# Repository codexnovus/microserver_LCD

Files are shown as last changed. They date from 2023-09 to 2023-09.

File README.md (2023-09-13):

# microserver_LCD
An LCD display for the microserver. See the documentation inside each folder for more information, or go to the [Hackaday project page](https://hackaday.io/project/192756-lcd-display-for-a-hp-g7-microserver)

Every folder contain its own documentation:
* arduino: schematics, and project files for the arduino part
* enclosure: 3D model and ready-to-print files
* node: Node.js project to run the system from the PC
* references: reference files, documentation, links and credits

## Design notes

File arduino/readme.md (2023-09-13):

# Arduino Code

This part of the project borrows heavily from [arduino-lcdproc](https://github.com/TimeTravel-0/arduino-lcdproc) plus some tutorials.

The sketch initializes the screen, and has a timeout function when is not receiving data.

It also reads the status of the buttons and sends A or B whenever one is pressed.

Is not really complex, but doesn't need to be.

Using this script also has the nice extra bonus of being compatible with LCDProc serializer mode, though the buttons won't be supported.

# The circuit

The circuit is fairly simple, the only complication is finding the proper resistance wiper for your project. Mine could have used a 30K. At 20K it simply goes from nothing until you reach like 90% and then it kicks right in into the visible territory. 

My screen did not have backlight: If yours has, it may be a good idea to put a resistor in the BLA pin. Arduino tutorials recommend 220 ohm.

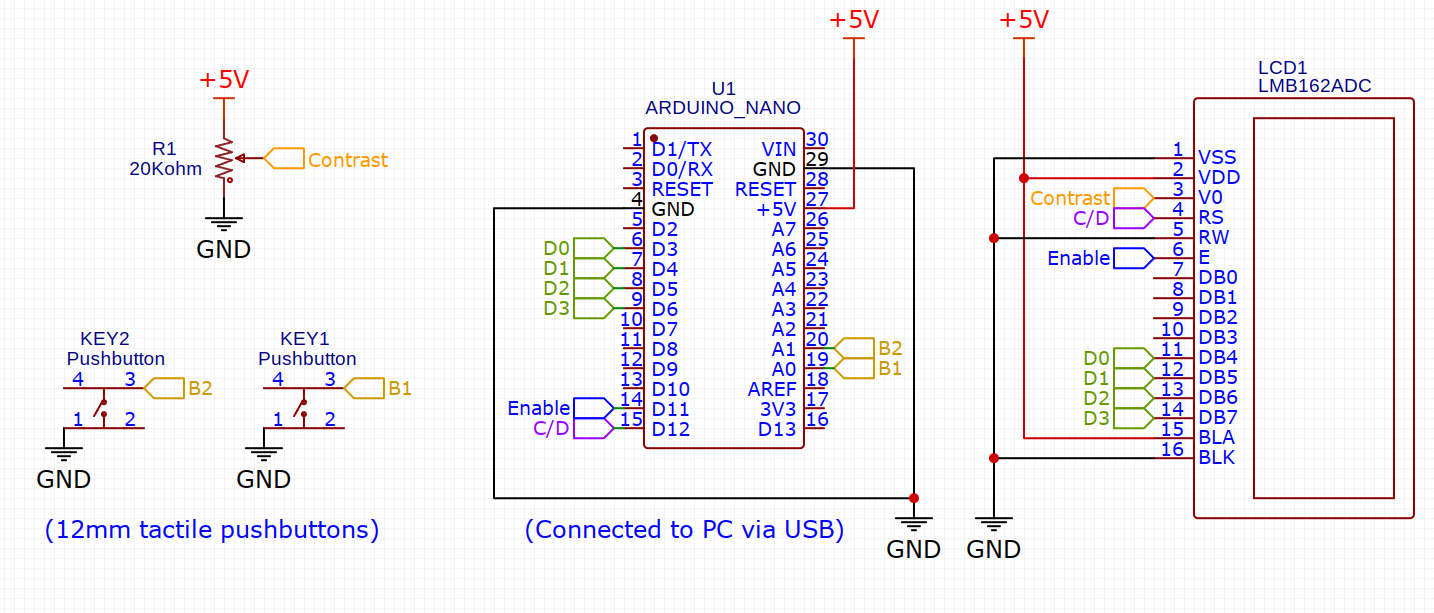
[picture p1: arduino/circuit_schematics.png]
The schematic


Originally This project embedded the circuit directly into the screen but I had issues routing the USB cable so I ended up separating the circuit and routing everything with cables. On the other hand this simplifies cable routing enormously.

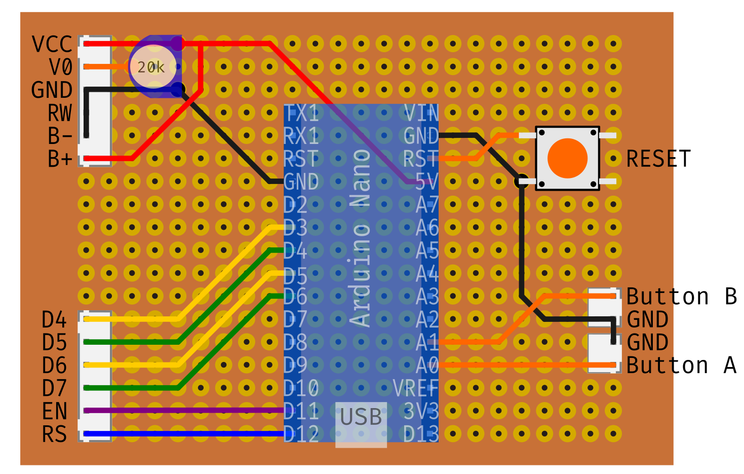
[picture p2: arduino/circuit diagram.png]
The diagram


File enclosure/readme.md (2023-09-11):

# The 3D model
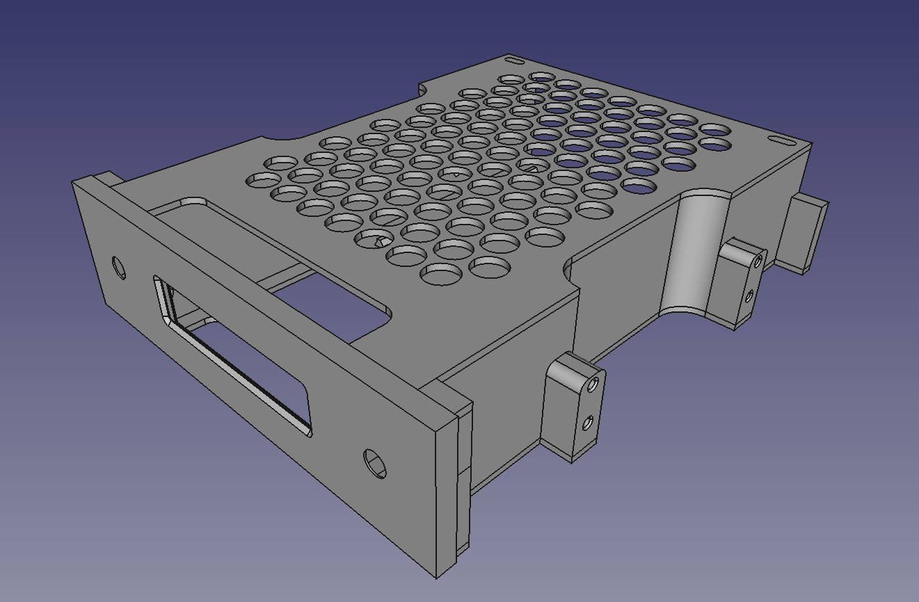
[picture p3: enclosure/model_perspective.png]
The model

The model consists of a base that (loosely) follows the CD-ROM standard measures that you can find on the "References" folder, a faceplate that houses the screen and the buttons, and a top cover that ties everything in a nice package. It has a space for fitting a 2.5 inch hard drive.

Everything is either press fitted, or secured with M3/M4 screws.

One could modify only the faceplate to fit a different LCD if needed, though most HD44780 clones I've seen have similar measures.

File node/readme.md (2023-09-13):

# The computer-side app
This app is written in node.js and requires the serialport and systeminformation libraries. The app is written for Linux in mind but there should be no reason it cannot run in Windows by changing the port reference, and modifying the screen functions that handle OS-specific situations, like the hard disk stats. Systeminformation tries to be as OS-agnostic as possible so things like CPU, Memory, Network Interfaces... should work out of the box.

## The app structure
The app will open the serial port defined in the lcd object and will call a _screen function_ once per second. It will also listen for pushbutton events that will change which screen is active.

## The screen functions
The screen functions are self contained: They retrieve the data from systeminformation and update the LCD screen.
There are currently four:
* screen_hostname: displays current local IP and hostname
* screen_diskinfo: retrieves hard drive usage and label or path and displays the first two.
* screen_heartbeat: displays CPU, RAM, and Network usage
* screen_uptime: displays system uptime

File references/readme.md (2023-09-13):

# Documents
* SF-8551.PDF: Specifications for CD-ROM drives. The last two pages include all measurements you need to make your own 5 1/2 inch half height enclosure.
* HD44780U.PDF: Datasheet for the original chip. Includes specific documentation about how characters are stored that most pages ignore.

# Links
* [systeminformation node library](https://systeminformation.io): This is the library I used to collect info from the system
* [serialport library](https://serialport.io): This is the library that enables node.js interface with the LCD

# Images
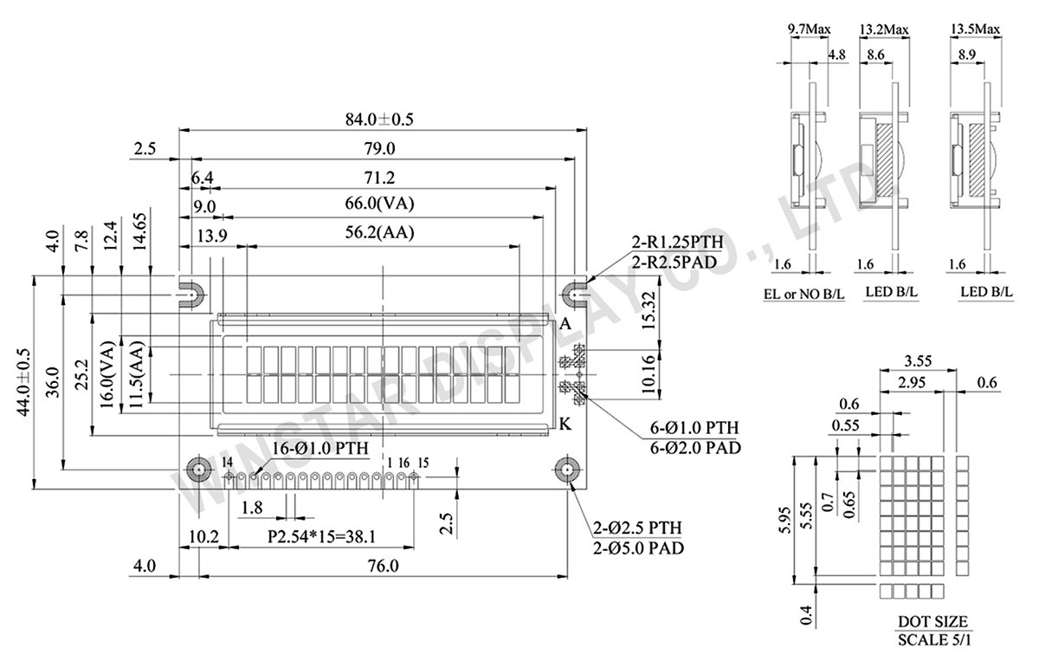
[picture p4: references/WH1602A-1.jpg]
LCD Specs

Physical specifications for the 1602 LCD. Most follow similar patterns. I checked mine against those with a caliper and fit decently.

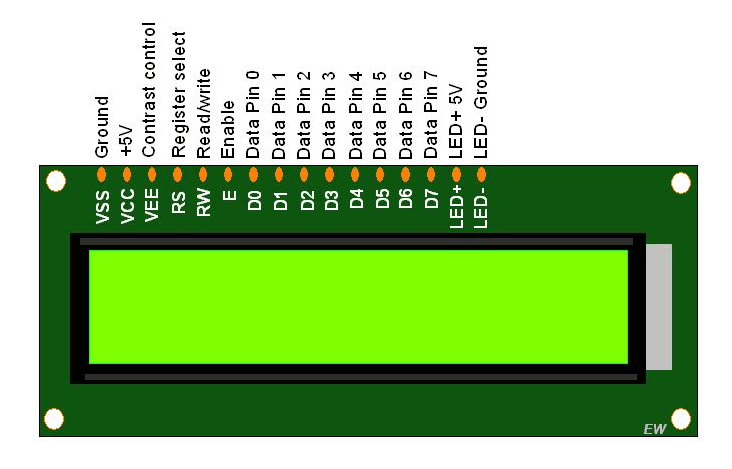
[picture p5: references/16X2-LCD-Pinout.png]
LCD Pinout

LCD pinout. Most of not all LCDs have the same pinout, but also they lack any kind of labeling so it is a good idea to have it handy.

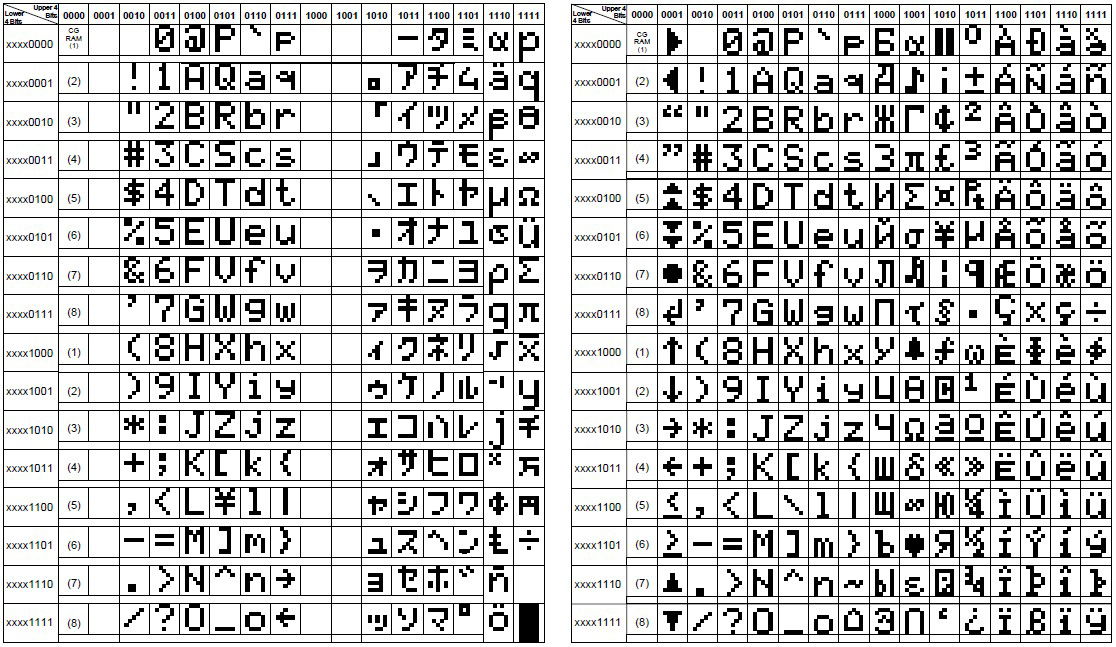
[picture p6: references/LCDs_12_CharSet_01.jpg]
LCD Charset

Charset map for the two more common ROMS.

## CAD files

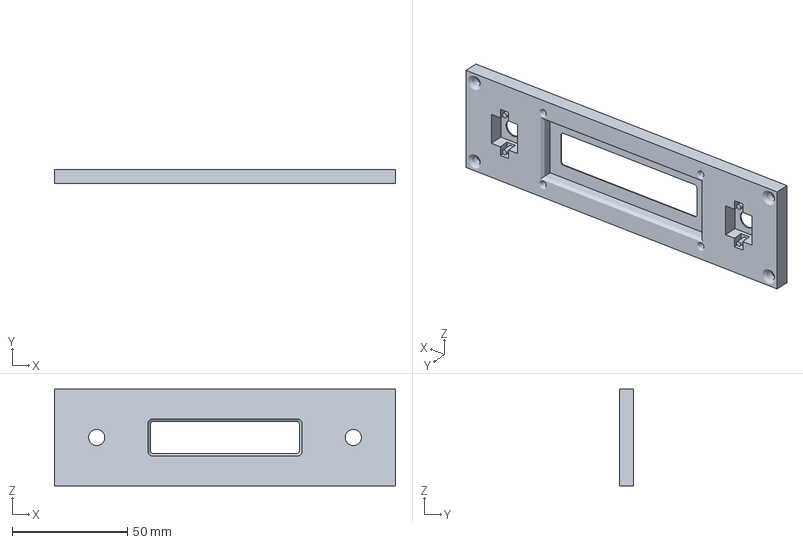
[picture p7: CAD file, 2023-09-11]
enclosure/LCD_Enclosure-Front Plate.3mf
148.0 x 6.00 x 42.0 mm

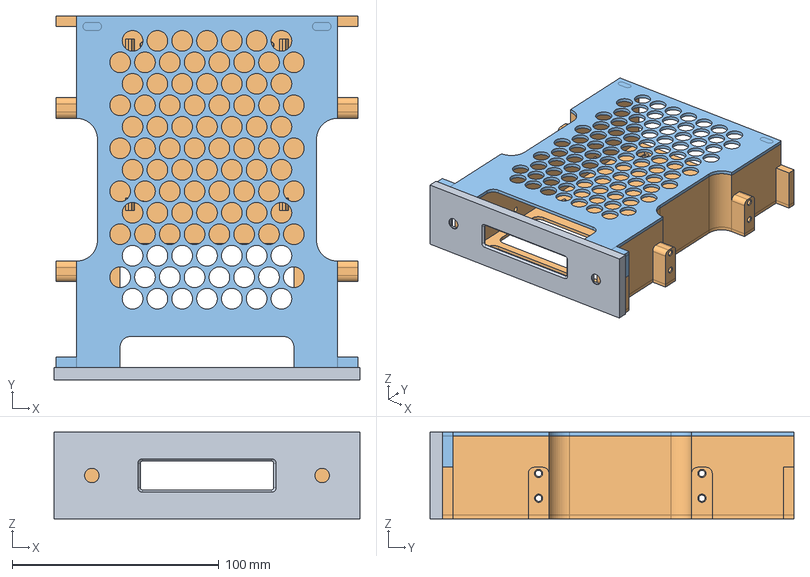
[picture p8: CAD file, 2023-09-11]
enclosure/LCD_Enclosure.FCStd
148.0 x 176.0 x 42.0 mm
Front Plate
Bottom Plate
Top Plate

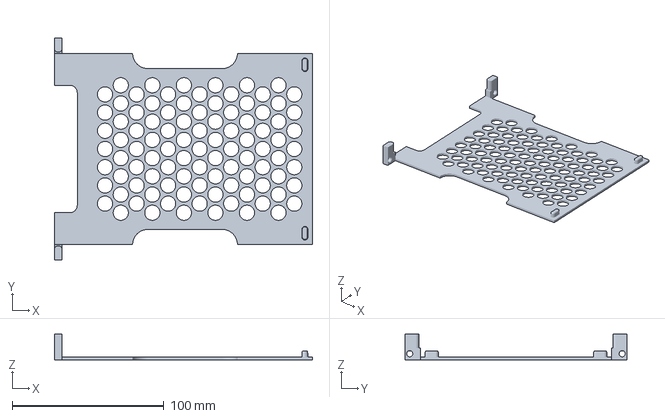
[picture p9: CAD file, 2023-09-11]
enclosure/LCD_Enclosure-Top Plate.3mf
170.0 x 146.0 x 17.0 mm

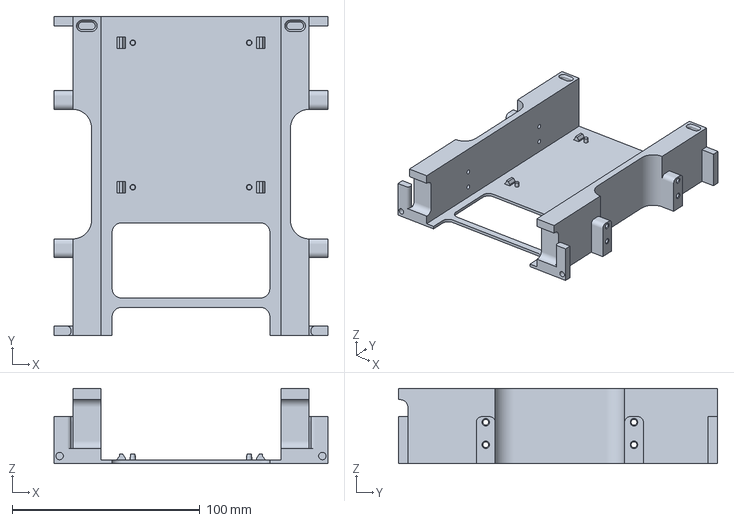
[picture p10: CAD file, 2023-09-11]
enclosure/LCD_Enclosure-Bottom Plate.3mf
146.0 x 170.0 x 40.0 mm

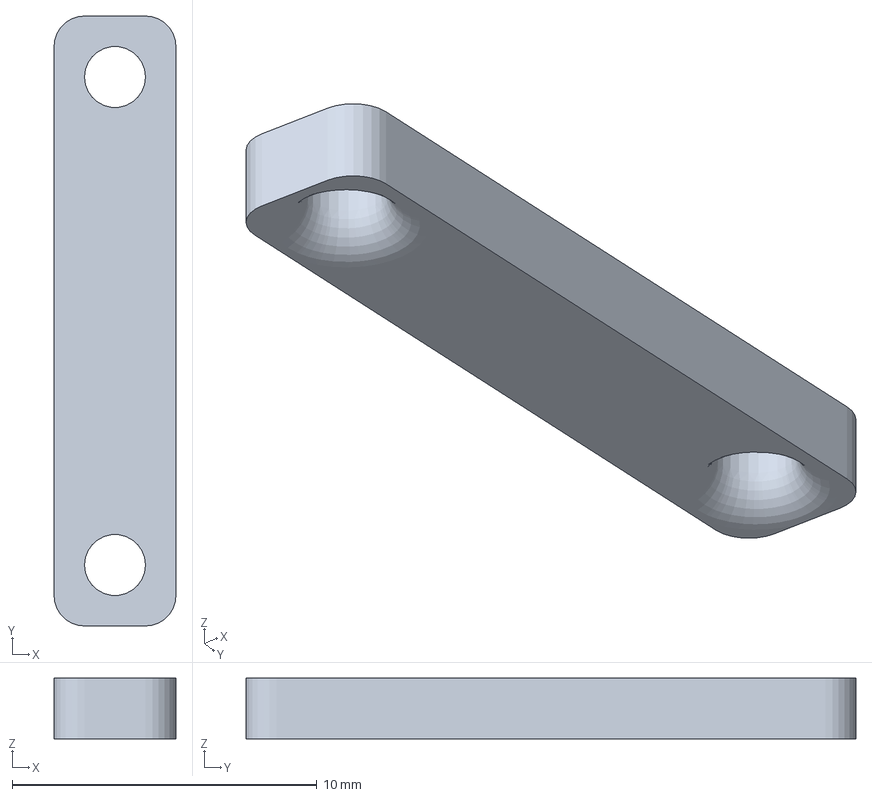
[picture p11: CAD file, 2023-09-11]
enclosure/LCD_Enclosure-Latches.3mf
4.00 x 20.0 x 2.00 mm

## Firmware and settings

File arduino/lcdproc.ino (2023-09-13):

/*

 The circuit:
 * LCD RS pin to digital pin 12
 * LCD Enable pin to digital pin 11
 * LCD D4 pin to digital pin 5
 * LCD D5 pin to digital pin 4
 * LCD D6 pin to digital pin 3
 * LCD D7 pin to digital pin 2
 * LCD R/W pin to ground
 * 10K resistor:
 * ends to +5V and ground
 * wiper to LCD VO pin (pin 3)

Arduino code based on liquid crystal library + lcdproc source code
(see https://github.com/lcdproc/lcdproc/blob/master/server/drivers/hd44780-serial.h, HD44780_CT_LCDSERIALIZER)

 http://www.arduino.cc/en/Tutorial/LiquidCrystalSerialDisplay

*/


// include the library code:
#include <LiquidCrystal.h>

// UART config
const int baud = 9600;
const int escapeByte = 0xFE;

// display pinning & dimensions
const int rs = 12, en = 11, d4 = 3, d5 = 4, d6 = 5, d7 = 6;
const int rows = 2;
const int colums = 16;
const byte uparrow[8] = {
  B00000,
  B00100,
  B01110,
  B10101,
  B00100,
  B00100,
  B00000,
  B00000
};

const byte downarrow[8] = {
  B00000,
  B00100,
  B00100,
  B10101,
  B01110,
  B00100,
  B00000,
  B00000
};

// initialize the library by associating any needed LCD interface pin
// with the arduino pin number it is connected to
LiquidCrystal lcd(rs, en, d4, d5, d6, d7);

void setup() {
  // set up the LCD's number of columns and rows:
  lcd.begin(colums, rows);
  
  // initialize the serial communications:
  Serial.begin(baud);

  // give hint on how to send data to display
  lcd.createChar(0, uparrow);
  lcd.createChar(1, downarrow);
  lcd.clear();
  lcd.print("Inicializando");
  lcd.setCursor(0,1);
  lcd.print("pantalla");
  pinMode(A1, INPUT_PULLUP);
  pinMode(A2, INPUT_PULLUP);
  
}

// for instruction escape logic
uint8_t c = 0xFF;
bool instructionEscape = false;

// for timeout display logic
uint32_t timeoutCounter = 1;
uint32_t lastTimeReception = 0;

// for button pressing logic
bool aIsPressed = false;
bool bIsPressed = false;
 
void loop()
{
    // logic to show message in case of no update
    timeoutCounter+=1;
    if((timeoutCounter>2000000) && (timeoutCounter%1000)==0)
    {
        // calculate time
        uint32_t seconds = ((millis()/1000) - lastTimeReception); // overflow might happen!
        int minutes = seconds/60;
        int hours = minutes/60;
        seconds = seconds%60;
        minutes = minutes%60;
        char timestring[20];
        snprintf(timestring,20,"%04d:%02d:%02d",hours,minutes,seconds);

        lcd.clear();
        lcd.print("Desconectado");
        lcd.setCursor(0,1);        
        lcd.print(timestring);
    }

    while (Serial.available() > 0)
    {
        timeoutCounter=0;
        lastTimeReception = millis()/1000;
        // display each character to the LCD
        c = Serial.read();

        // last char was escape character
        if(instructionEscape == true)
        {
            instructionEscape = false;
            lcd.command(c);
        }
        else
        {
            if((c == escapeByte) ) // command escape character
            {
                instructionEscape = true;
            }
            else
            {
                lcd.write(c);  
            }  
        }
    }
   
   int buttonA = digitalRead(A1);
   int buttonB = digitalRead(A2);
   if (buttonA == HIGH && aIsPressed == false) {
    aIsPressed = true;
    Serial.write("A");
   }
   if (buttonA == LOW && aIsPressed == true) {
    aIsPressed = false;
   }
    if (buttonB == HIGH && bIsPressed == false) {
    bIsPressed = true;
    Serial.write("B");
   }
   if (buttonB == LOW && bIsPressed == true) {
    bIsPressed = false;
   }
}

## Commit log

2023-09-11 Adding basic information
    [LCD_Enclosure-Bottom Plate.3mf, LCD_Enclosure-Front Plate.3mf, LCD_Enclosure-Latches.3mf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]
2023-09-13 Added two custom characters to LCDproc.ino Fixed overflow bug in LCDproc.ino
    [lcdproc.ino]
2023-09-13 added circuit diagram
2023-09-13 added circuit diagram to arduino documentation
